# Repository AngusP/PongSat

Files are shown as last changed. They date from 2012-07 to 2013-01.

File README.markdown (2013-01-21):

<h3>PongSat Environment Sensing Datalogger</h3>

<h4>NOTICE: This isn't finished yet!!! I wouldn't try making one...</h4>

<p>The PongSat has a barometric pressure sensor, a humidity sensor, a temperature 
sensor and I2C bus for a 9DoF sensor stick (<a href=""http://www.sparkfun.com/products/10724">
SEN-10724</a>) which has on it an Accelerometer, Magnetometer and Gyroscope. The board
uses 3.3 volt logic and power.</p>

<p>This is a double sided PCB that will be able to fit inside a PingPong ball and 
so it can be used in JP Aeorspace's free Pongsat launches. All of the components are SMD, 
and so are pretty tiny, but can be harvested off a SparkFun OpenLog, and an Arduino Pro Micro 
(with the AtMega32u4).</p>

<p>Because of the 32u4 processor, this can be talked to and programmed via a USB Micro B 
connector, as commonly found on smartphone chargers. There is a I2C header with 3V3 and GND, 
but there is no FTDI or other serial connector other than the USB.</p>

<p>Because this is designed to fit in a pingpong ball, powering it can be difficult, so it 
is recommended to use two 3 volt coin cell batteries to get a total of 6 volts. The 
batteries should last a long time, but if you can find a small LiPo I'd strongly recommend 
using that.</p>

<p>None of these have ever been made in any way shape or form, so there is absolutely no 
guarantee of it being assemble-able, let alone functional. You do that at your own risk. 
After I have made on then I will say whether it works or not...</p>

<p>This project is in the public domain.</p>

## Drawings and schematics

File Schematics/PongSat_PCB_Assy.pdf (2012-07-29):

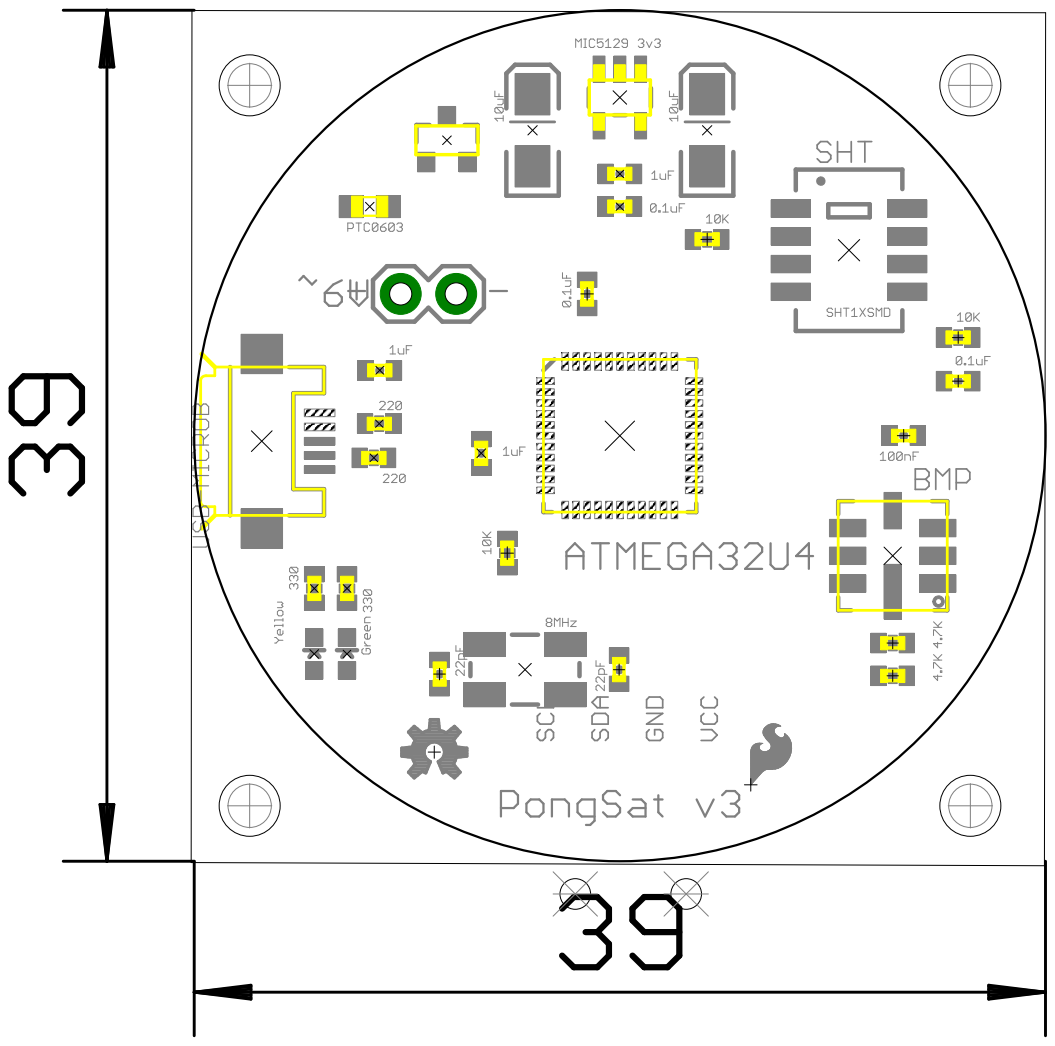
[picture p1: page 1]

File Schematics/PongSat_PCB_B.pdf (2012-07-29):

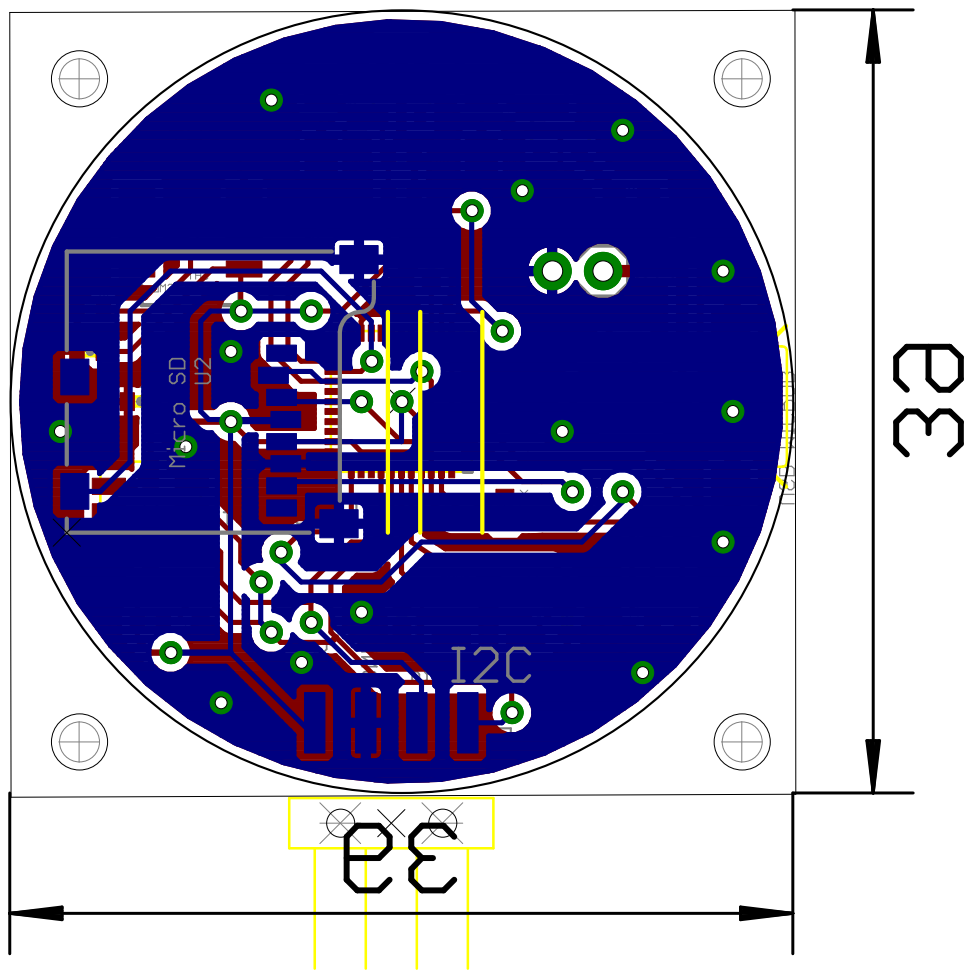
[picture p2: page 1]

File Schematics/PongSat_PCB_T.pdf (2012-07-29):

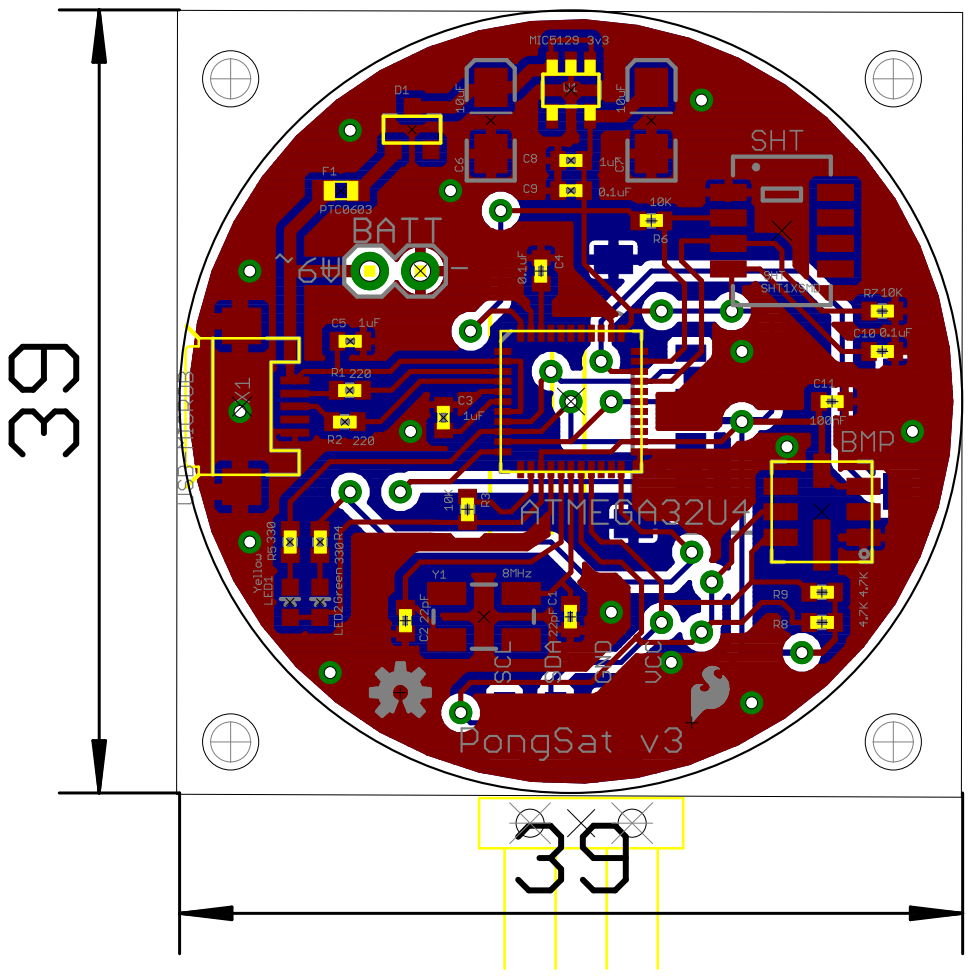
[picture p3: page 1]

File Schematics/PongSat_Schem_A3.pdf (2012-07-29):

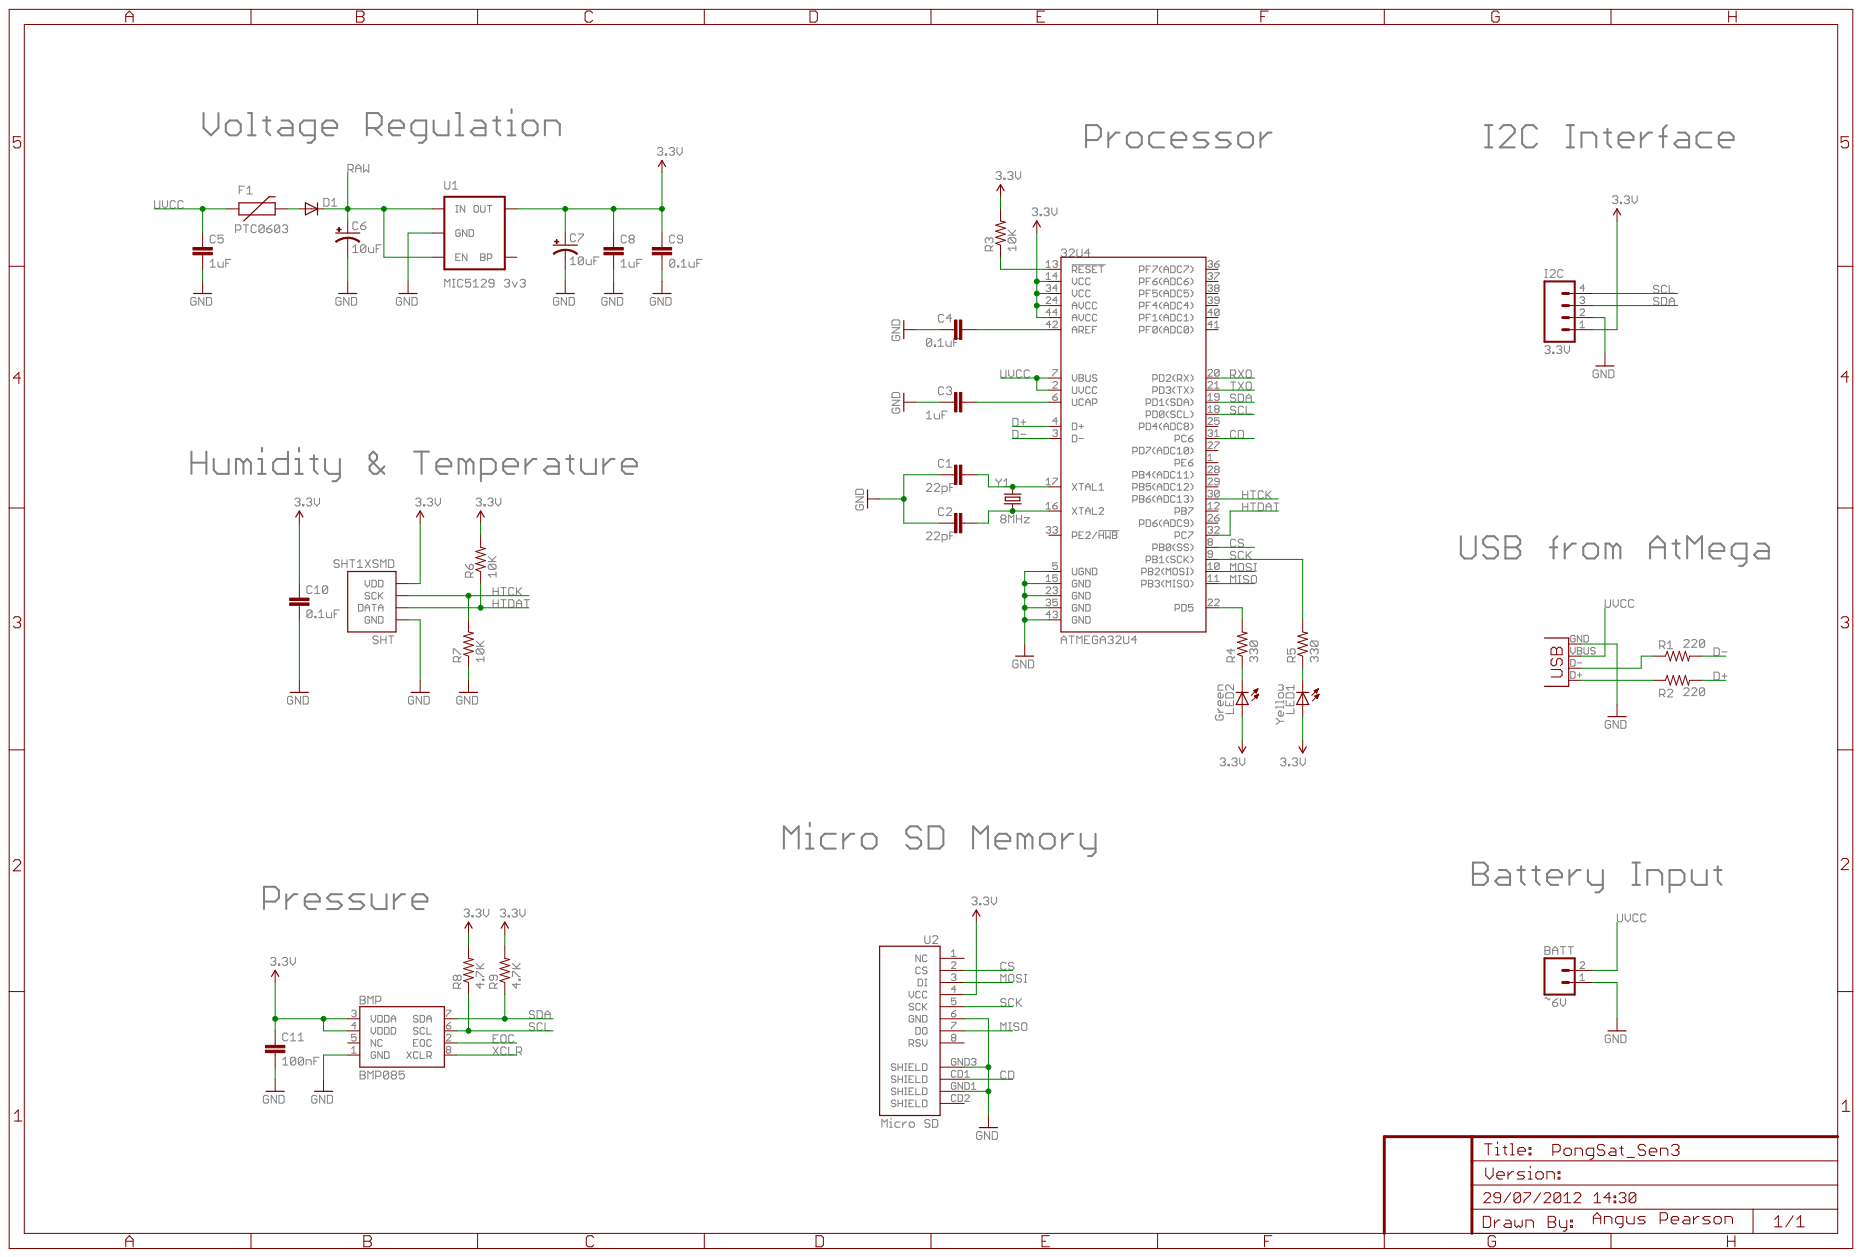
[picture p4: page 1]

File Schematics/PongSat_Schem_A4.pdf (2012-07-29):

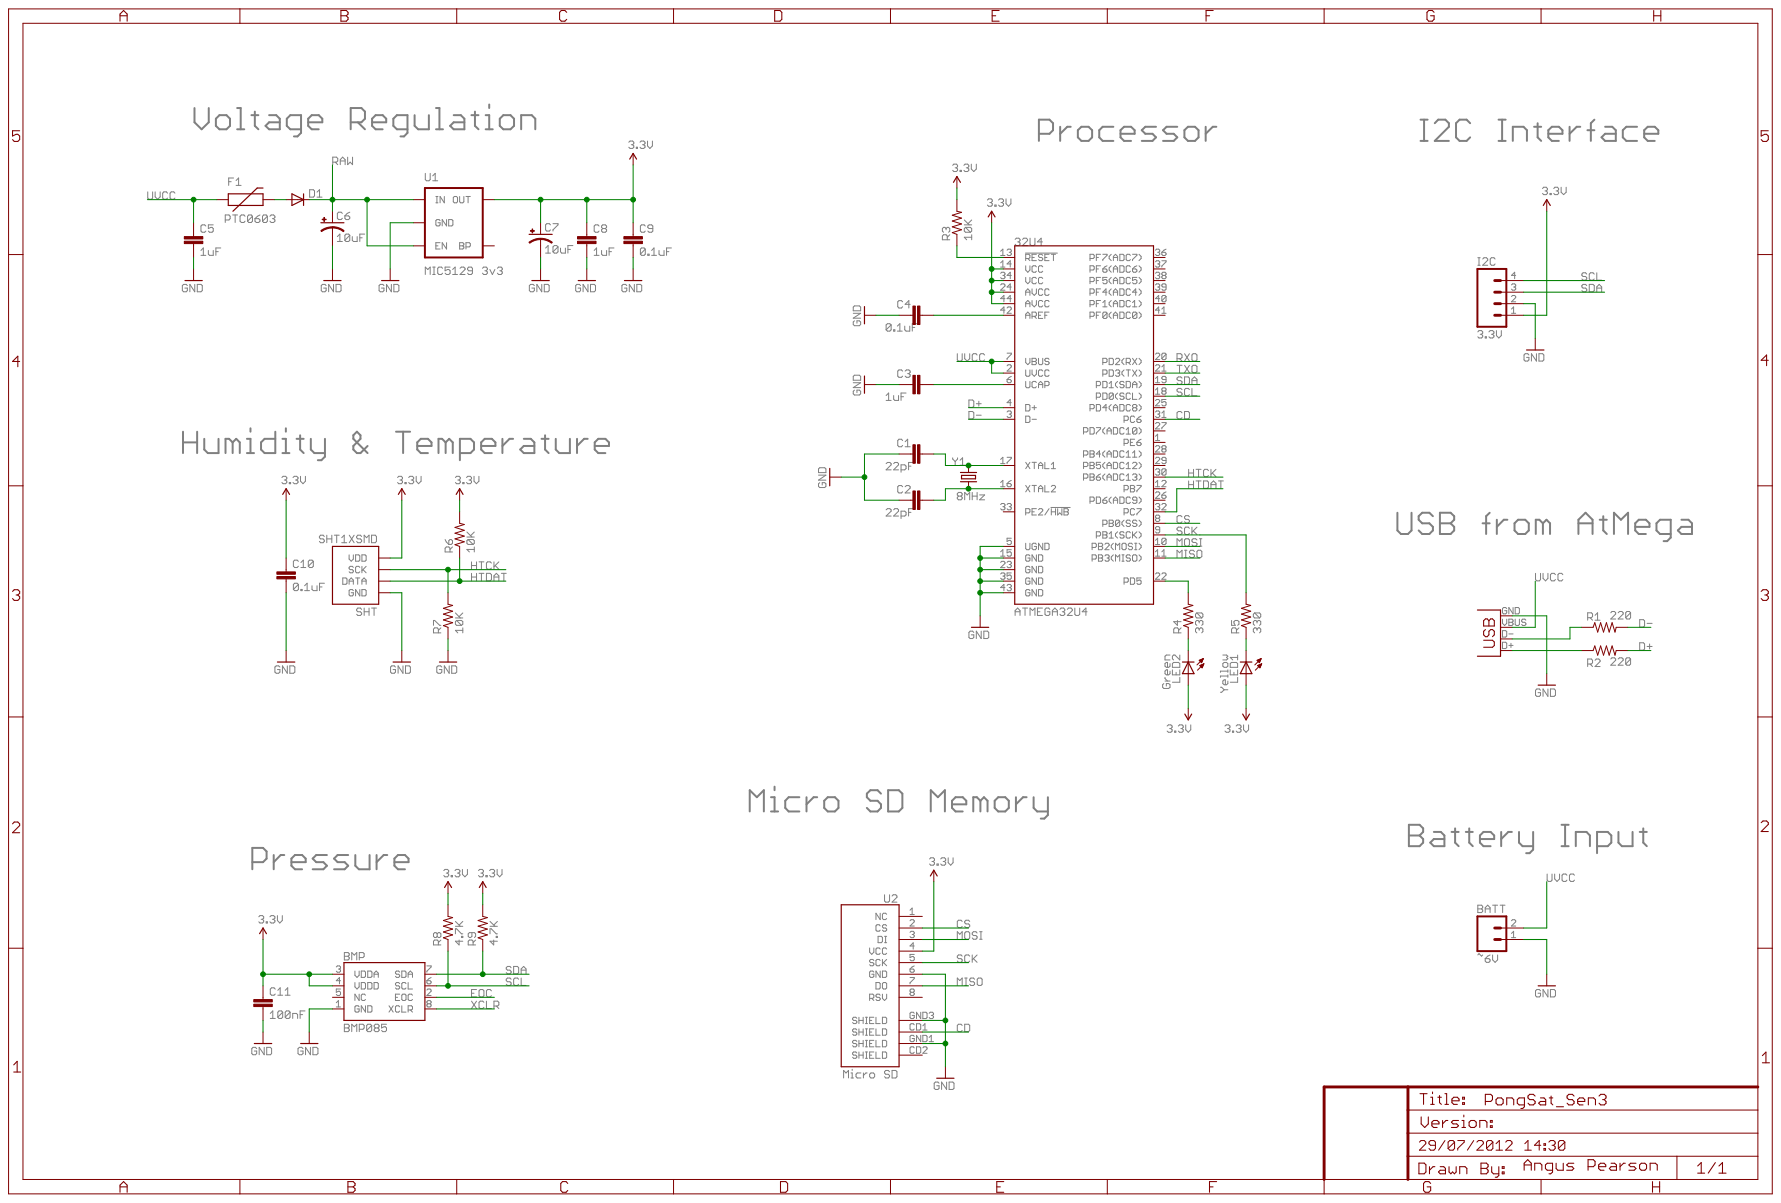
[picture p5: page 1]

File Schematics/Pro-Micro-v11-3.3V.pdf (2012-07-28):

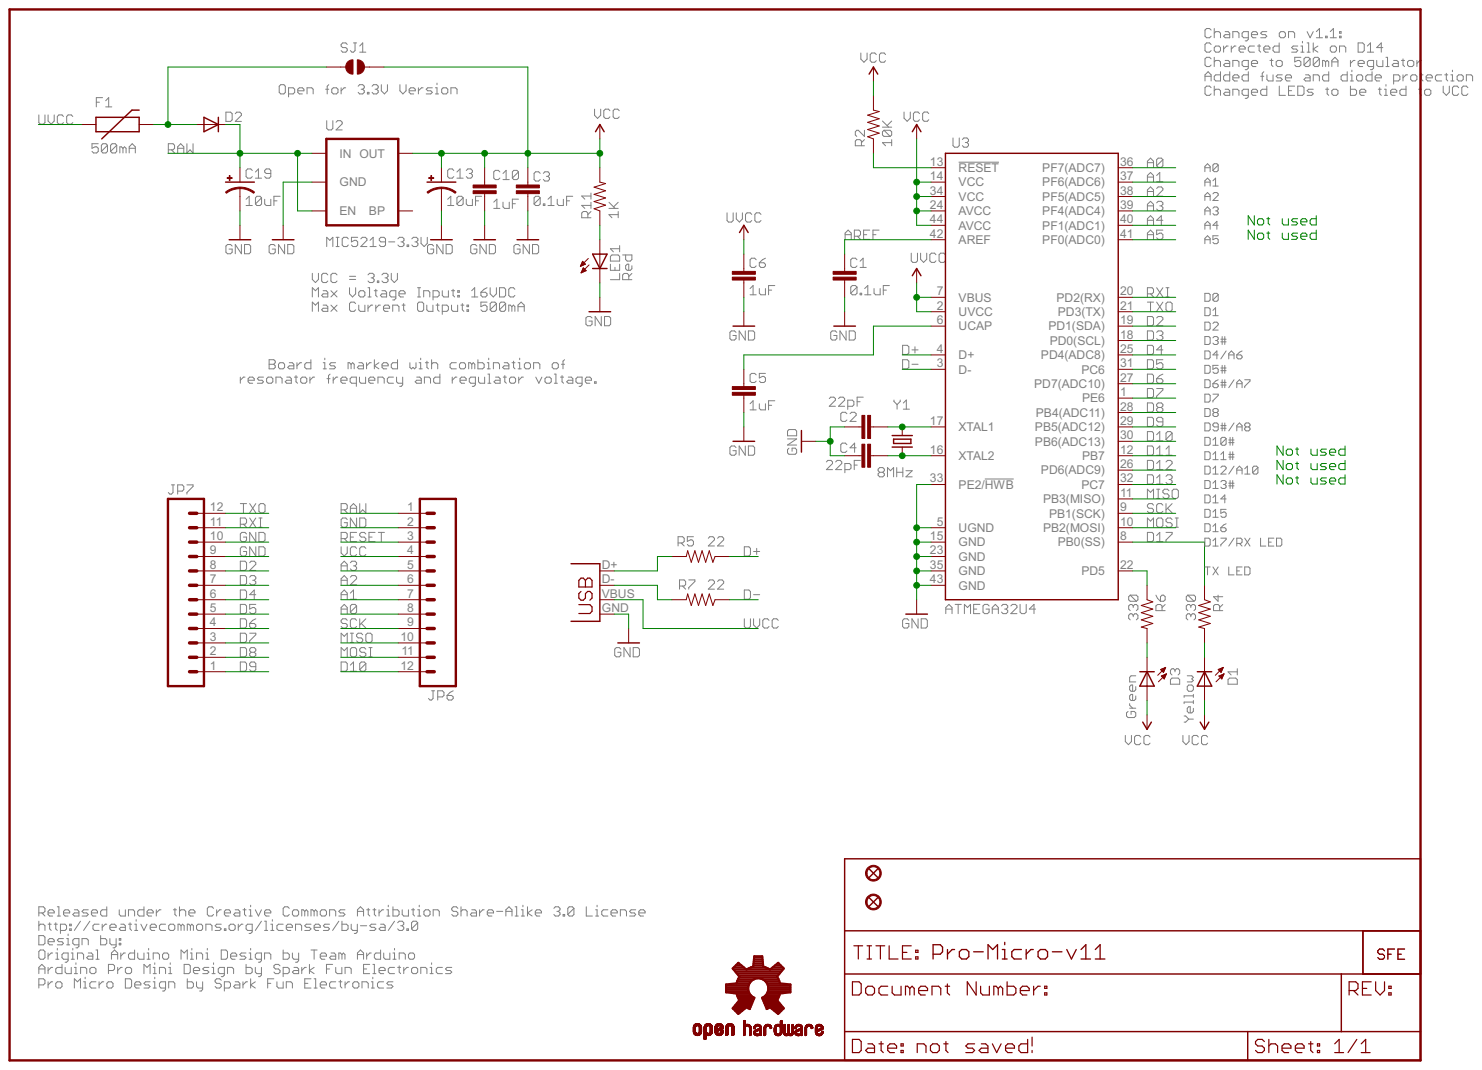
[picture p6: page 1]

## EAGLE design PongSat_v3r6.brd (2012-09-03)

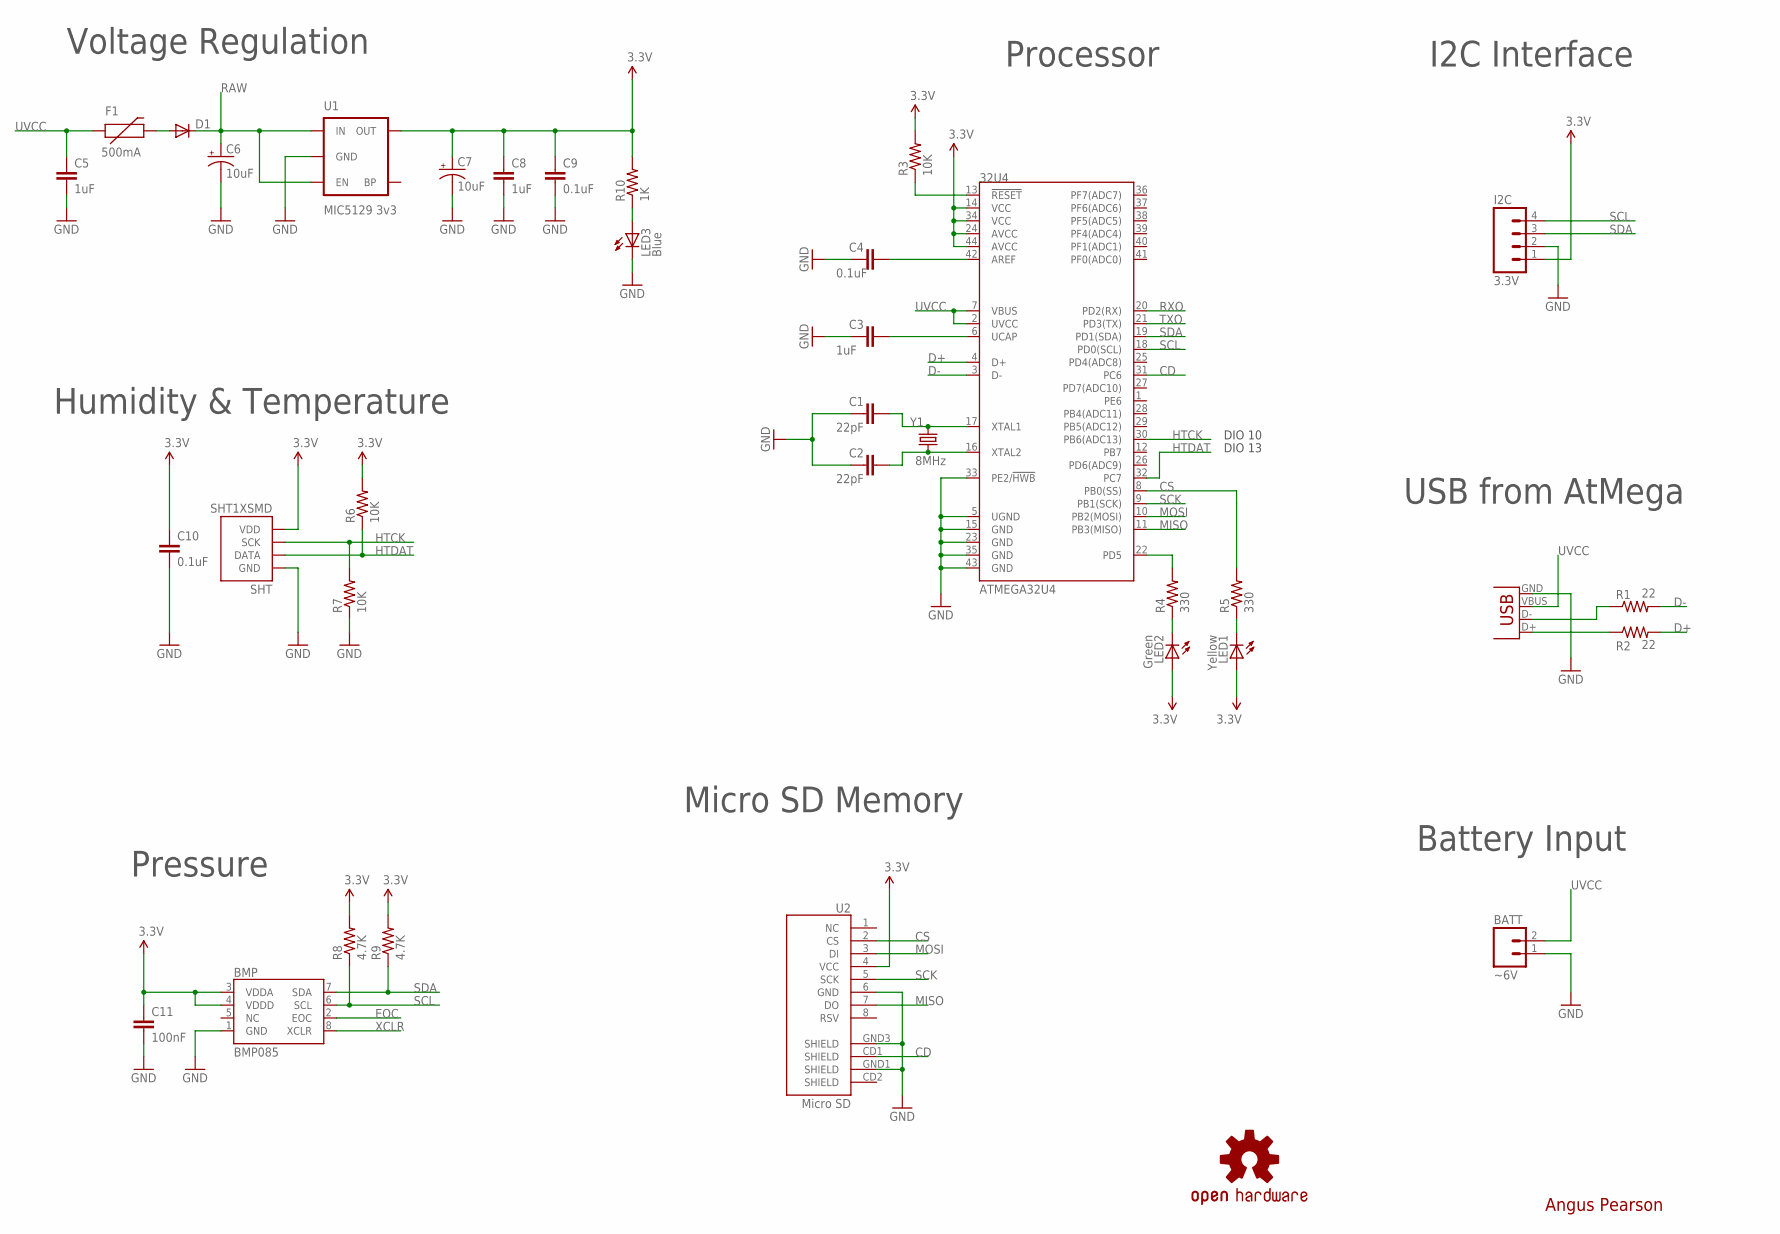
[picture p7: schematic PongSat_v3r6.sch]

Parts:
32U4: ATMEGA32U4; QFN-44-NOPAD
BATT: ~6V; 1X02
BMP: BMP085
C1, C2: 22pF; 0402-CAP
C3, C5, C8: 1uF; 0402-CAP
C4, C9, C10: 0.1uF; 0402-CAP
C6, C7: 10uF; EIA3216-KIT
C11: 100nF; 0402-CAP
D1: DIODESOT23; SOT23-3
F1: 500mA; 0603
I2C: 3.3V; 1X04
LED1: Yellow; LED-0603
LED2: Green; LED-0603
LED3: Blue; LED-0603
R1, R2: 22; 0402-RES
R3, R6, R7: 10K; 0402-RES
R4, R5: 330; 0402-RES
R8, R9: 4.7K; 0402-RES
R10: 1K; 0402-RES
SHT: SHT1XSMD; SHT1X
U1: MIC5129 3v3; SOT23-5
U2: Micro SD; MICRO-SD-SOCKET-PP
U$2: OSHW-LOGOS; OSHW-LOGO-S
X1: USB-MICROB
Y1: 8MHz; CRYSTAL-SMD-5X3

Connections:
3.3V: 32U4.14 (VCC), 32U4.24 (AVCC), 32U4.34 (VCC), 32U4.44 (AVCC), BMP.3 (VDDA), BMP.4 (VDDD), C7.A (+), C8.1, C9.1, C10.1, C11.1, I2C.1, LED1.A, LED2.A, R3.2, R6.2, R8.2, R9.2, R10.2, SHT.4 (VDD), U1.5 (OUT), U2.4 (VCC)
CD: 32U4.31 (PC6), U2.CD1 (SHIELD)
CS: 32U4.8 (PB0(SS)), R5.2, U2.2 (CS)
D+: 32U4.4 (D+), R2.2
D-: 32U4.3 (D-), R1.2
EOC: BMP.2 (EOC)
GND: 32U4.5 (UGND), 32U4.15 (GND), 32U4.23 (GND), 32U4.33 (PE2/!HWB), 32U4.35 (GND), 32U4.43 (GND), BATT.1, BMP.1 (GND), C1.1, C2.1, C3.1, C4.1, C5.2, C6.C (-), C7.C (-), C8.2, C9.2, C10.2, C11.2, I2C.2, LED3.C, R7.1, SHT.1 (GND), U1.2 (GND), U2.6 (GND), U2.GND1 (SHIELD), U2.GND3 (SHIELD), X1.GND
HTCK: 32U4.30 (PB6(ADC13)), R7.2, SHT.3 (SCK)
HTDAT: 32U4.32 (PC7), R6.1, SHT.2 (DATA)
MISO: 32U4.11 (PB3(MISO)), U2.7 (DO)
MOSI: 32U4.10 (PB2(MOSI)), U2.3 (DI)
unnamed: 32U4.16 (XTAL2), C2.2, Y1.1
unnamed: 32U4.17 (XTAL1), C1.2, Y1.3 (2)
unnamed: R1.1, X1.D-
unnamed: R2.1, X1.D+
unnamed: 32U4.6 (UCAP), C3.2
unnamed: LED2.C, R4.1
unnamed: LED1.C, R5.1
unnamed: LED3.A, R10.1
unnamed: 32U4.13 (!RESET), R3.1
unnamed: 32U4.42 (AREF), C4.2
unnamed: D1.1 (A), F1.2
RAW: C6.A (+), D1.3 (C), U1.1 (IN), U1.3 (EN)
RXO: 32U4.20 (PD2(RX))
SCK: 32U4.9 (PB1(SCK)), U2.5 (SCK)
SCL: 32U4.18 (PD0(SCL)), BMP.6 (SCL), I2C.4, R8.1
SDA: 32U4.19 (PD1(SDA)), BMP.7 (SDA), I2C.3, R9.1
TXLED: 32U4.22 (PD5), R4.2
TXO: 32U4.21 (PD3(TX))
UVCC: 32U4.2 (UVCC), 32U4.7 (VBUS), BATT.2, C5.1, F1.1, X1.VBUS
XCLR: BMP.8 (XCLR)

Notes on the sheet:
Angus Pearson
Voltage Regulation
Processor
Micro SD Memory
Pressure
Humidity & Temperature
I2C Interface
USB from AtMega
Battery Input
DIO 10
DIO 13

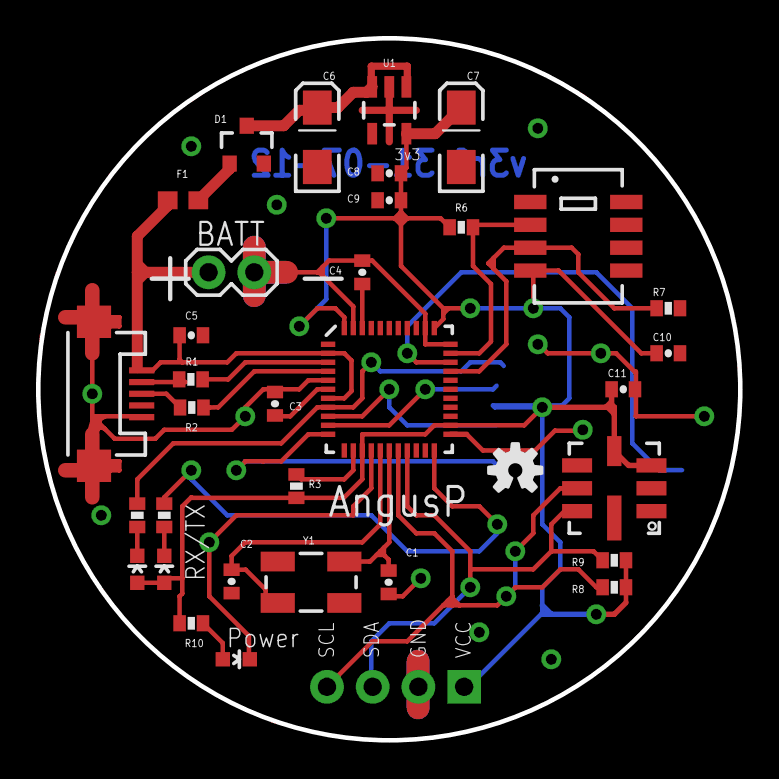
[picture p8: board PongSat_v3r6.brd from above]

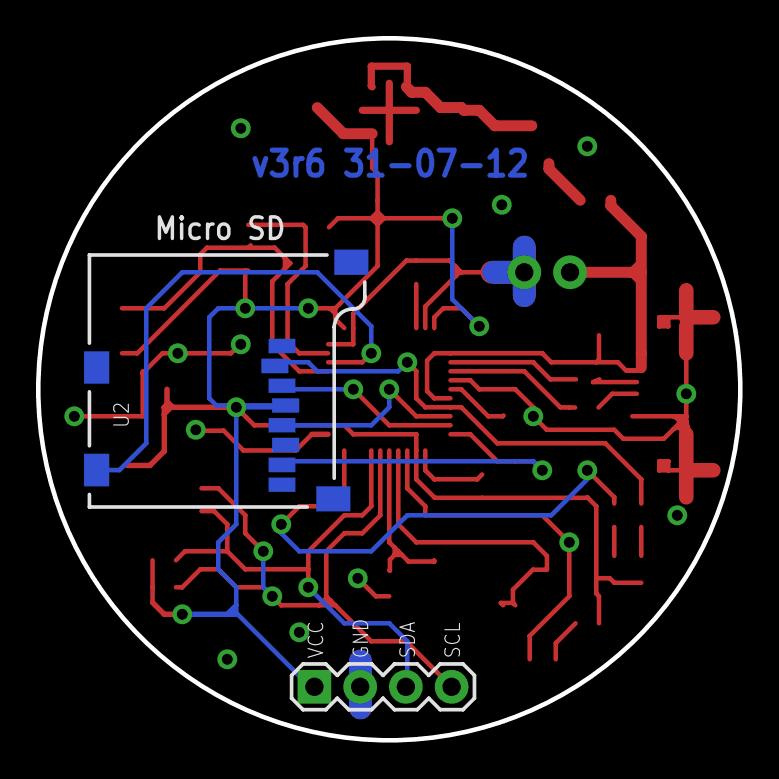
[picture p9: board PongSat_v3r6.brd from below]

Board: 2 copper layers, 39.0 x 39.0 mm, 36 parts (2 on the bottom side), 27 nets.

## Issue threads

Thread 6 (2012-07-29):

Extreme Environment testing

AngusP, 2012-07-29:
Environment testing of first -20C for 5 hours then -55C for a similar time period will need to be conducted. Pressure tests at room temperature and 0.001 ATM pressure will also need to be conducted. A test at <0.0005 ATM (Basically Vacuum) would be ideal. If the PCB failed then we would have to revert back to a much earlier design stage, most likely Milestone 'PCB Validation'.

If possible exposure to solar radiation and intense UV/IR light (Upper atmosphere conditions) would be great.

Closed 2019-08-29.

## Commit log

2012-07-28 Added v3 PCB
    Version 3 BETA (Vs 1 and 2 were alpha) PCB EAGLE files to repo. No
    Arduino code *yet*. Various Schematics from similar setups also added.
    [PongSat_Sen3.brd, PongSat_Sen3.sch]
2012-07-28 Updated PCB
    Completed PCB (V3 BETA) uploaded. PCB is now produceable, but not ERC'd
    or DRC'd.
    [PongSat_Sen3.brd, PongSat_Sen3.sch]
2012-07-28 PCB Update
    Updated PCB with SD fix and also added new Schematics to repo.
    [PongSat_Sen3.brd, PongSat_Sen3.sch]
2012-07-29 Updated PCB V3 Rev 3
    Updated PCB with new Silkscreen, improved routing and placement, bias
    and mounting holes. Included Schematics, PCB Printouts and Assembly
    diagrams in repo :-)
    [PongSat_Sen3.brd, PongSat_Sen3.sch]
2012-07-29 Updated PCB and Gerbers
    Updated PCB with SilkScreen Fixes and also added Gerber Files to repo.
    Reorganised the directory structure to get data sheets and schematics
    out of the way. Also removed PCB versions 1 and 2 from repo.
    [Fio-v30.brd, Fio-v30.sch, OpenLog.brd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]
2012-07-29 Updated R4 Gerbers
2012-07-29 Updated to Version 3 Revision 5
    I2C header is now PTH, and various other slight tweaks have been
    applied. New Gerber filed also committed. Directory structure also
    simplified and reorganised.
    [Fio-v30.brd, Fio-v30.sch, OpenLog.brd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]
2012-07-31 Revision 6
    Removed acid traps and improved silkscreen. New rev 6 gerber files as
    well. Version 4 will be along soon in the main branch…
    [PongSat_v3r5.GBL, PongSat_v3r5.GTL, PongSat_v3r5.GTO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]
2012-07-31 Gerber Compatibility Trace Width DRC fix
    Fixed issue where Batch PCB rejected Gerbers with capitalised
    extensions, and enlarged bottom copper version and date tracking that
    failed BatchPCB DRC on width. Added fixed CAM job based on SparkFun
    Gerber generator that does not capitalise extensions.
    [PongSat_v3r6.brd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]
2012-09-03 Minor Fixes
    [PongSat_v3r6.brd, PongSat_v3r6.sch]
2012-09-05 Added a Bill of Materials

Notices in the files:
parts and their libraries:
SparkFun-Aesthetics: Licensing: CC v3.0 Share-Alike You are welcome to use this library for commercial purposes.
